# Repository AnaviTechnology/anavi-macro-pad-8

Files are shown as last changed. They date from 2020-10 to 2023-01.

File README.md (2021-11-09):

# ANAVI Macro Pad 8

**Open source, programmable, eight-key keypad with backlighting, underlighting, and OLED screen**

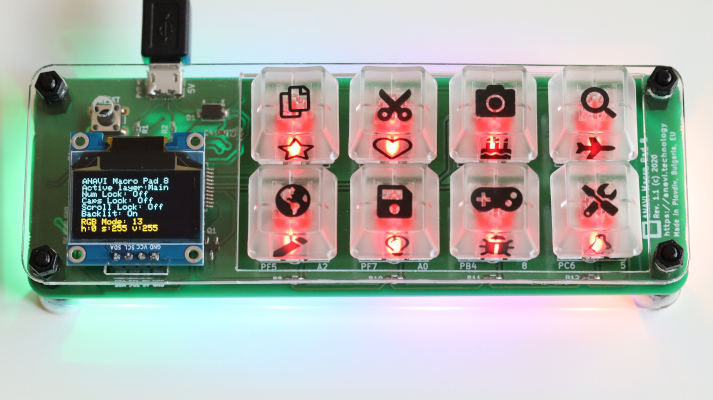
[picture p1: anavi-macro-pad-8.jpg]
ANAVI Macro Pad 8


ANAVI Macro Pad 8 is an open source, custom-programmable, mini 8-key keyboard/keypad. Each key can be reprogrammed to activate a macro or even a dedicated shortcut - all without any coding experience! Powered by the advanced, but easy-to-use [Quantum Mechanical Keyboard (QMK) open source firmware](https://github.com/qmk/qmk_firmware/tree/master/keyboards/anavi/macropad8).

ANAVI Macro Pad 8 has been designed with [the cross platform and open source electronics design automation suite KiCad](https://kicad.org/). [The acrylic enclosure](https://github.com/AnaviTechnology/anavi-cases/tree/master/anavi-macro-pad-8-case) has been designed with [OpenSCAD](https://www.openscad.org/).

[ANAVI Macro Pad 8 was successfully crowdfunded at Crowd Supply on 8 October 2020](https://www.crowdsupply.com/anavi-technology/anavi-macro-pad-8).

ANAVI Macro Pad 8 has been certified by [the Open Source Hardware Association under OSHWA UID BG000072 on July 13, 2020](https://certification.oshwa.org/bg000072.html).

For more details please visit https://anavi.technology/

# License

The project is released under the [Creative Commons Attribution-ShareAlike 4.0 International (CC BY-SA 4.0)](https://creativecommons.org/licenses/by-sa/4.0/).

Note: This is a human-readable summary of (and not a substitute for) the [license](https://creativecommons.org/licenses/by-sa/4.0/legalcode).

You are free to:

Share — copy and redistribute the material in any medium or format Adapt — remix, transform, and build upon the material for any purpose, even commercially. The licensor cannot revoke these freedoms as long as you follow the license terms. Under the following terms:

Attribution — You must give appropriate credit, provide a link to the license, and indicate if changes were made. You may do so in any reasonable manner, but not in any way that suggests the licensor endorses you or your use. ShareAlike — If you remix, transform, or build upon the material, you must distribute your contributions under the same license as the original. No additional restrictions — You may not apply legal terms or technological measures that legally restrict others from doing anything the license permits. Notices:

You do not have to comply with the license for elements of the material in the public domain or where your use is permitted by an applicable exception or limitation. No warranties are given. The license may not give you all of the permissions necessary for your intended use. For example, other rights such as publicity, privacy, or moral rights may limit how you use the material.

You will have to provide a link to the original creator of the project http://www.anavi.technology on any documentation or website.

Credit can be attributed through a link to the creator website: http://www.anavi.technology

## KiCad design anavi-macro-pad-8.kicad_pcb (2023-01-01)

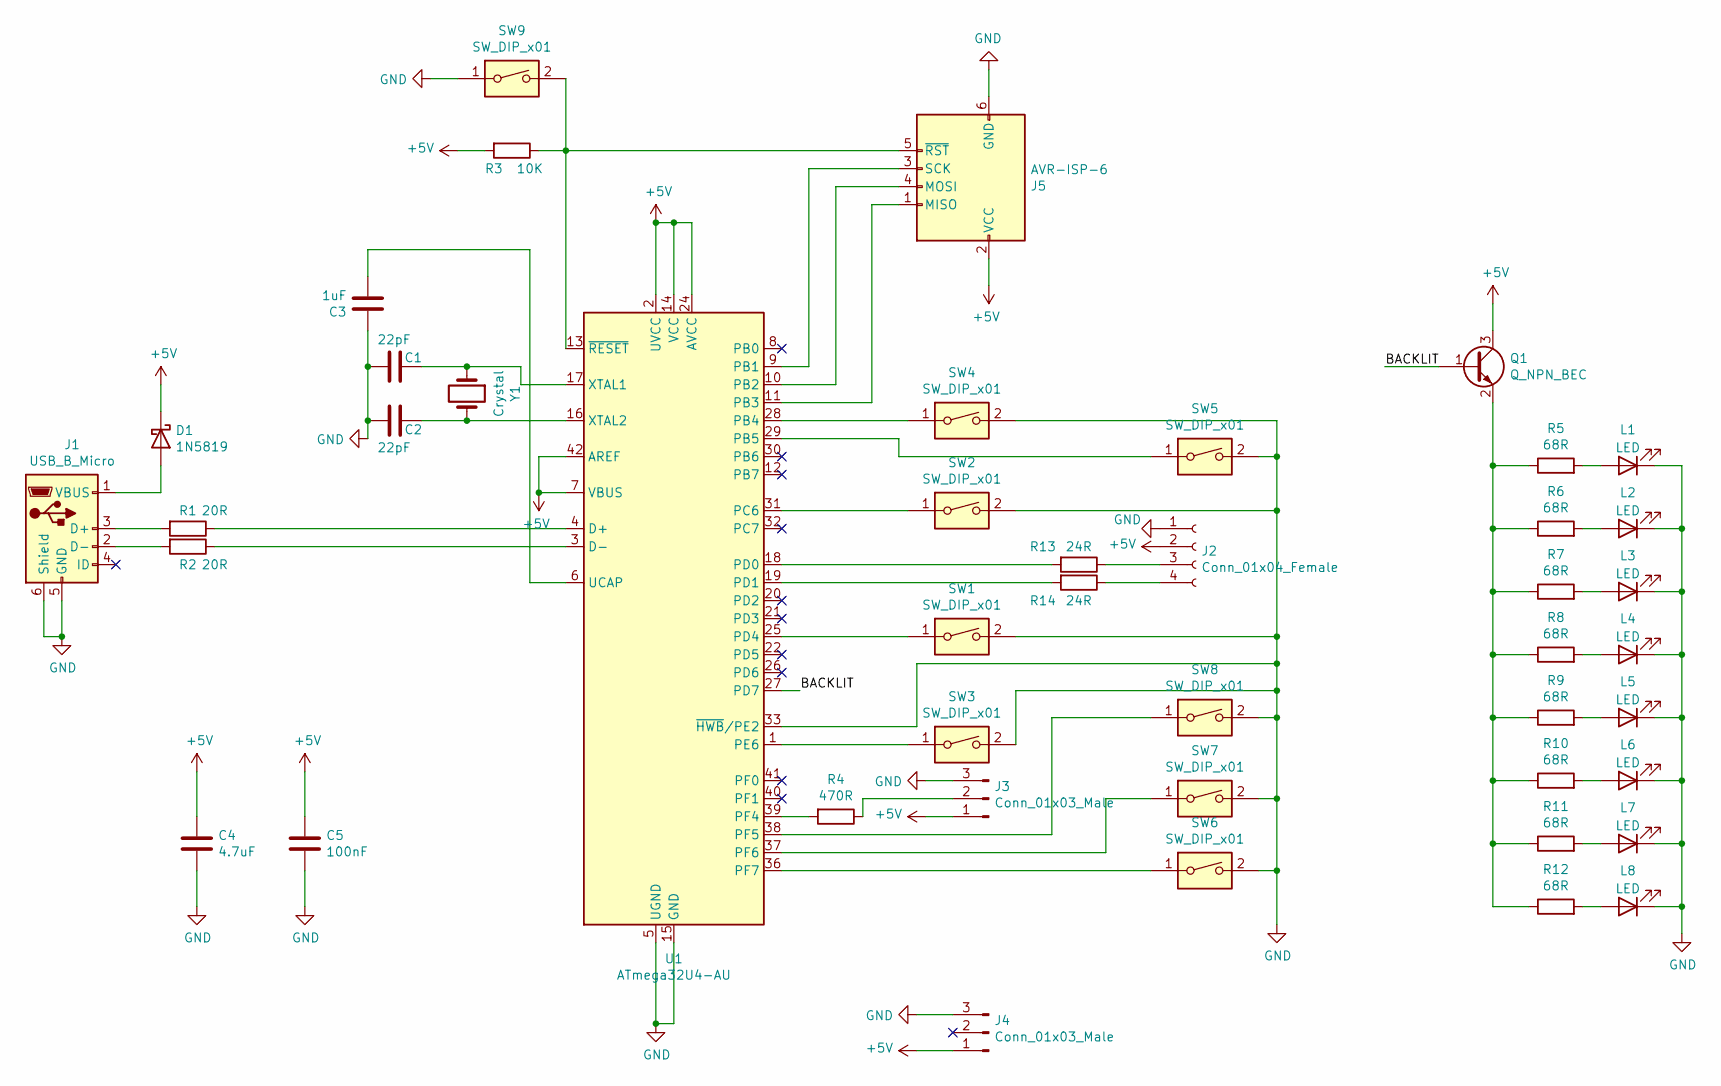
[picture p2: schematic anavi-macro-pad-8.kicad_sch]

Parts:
C1, C2: 22pF; C_0603_1608Metric
C3: 1uF; C_0603_1608Metric
C4: 4.7uF; C_0603_1608Metric
C5: 100nF; C_0603_1608Metric
D1: 1N5819; SMA_Standard
J1: USB_B_Micro; USB_Micro-B_Molex-105017-0001
J2: Conn_01x04_Female; PinHeader_1x04_P2.54mm_Vertical
J3, J4: Conn_01x03_Male; LedConnector_1x03_P2.54mm
J5: AVR-ISP-6; PinHeader_2x03_P2.54mm_Vertical
L1, L2, L3, L4, L5, L6, L7, L8: LED; LED_D3.0mm
Q1: Q_NPN_BEC; SOT-23
R1, R2: 20R; R_0603
R3: 10K; R_0603
R4: 470R; R_0603
R5, R6, R7, R8, R9, R10, R11, R12: 68R; R_0603
R13, R14: 24R; R_0603
SW1, SW2, SW3, SW4, SW5, SW6, SW7, SW8: SW_DIP_x01; SW_Cherry_MX_1.00u_Plate
SW9: SW_DIP_x01; SW_PUSH_6mm_h4.3mm
U1: ATmega32U4-AU; TQFP-44_10x10mm_P0.8mm
Y1: Crystal; Crystal_SMD_3225-4Pin_3.2x2.5mm_HandSoldering

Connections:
+5V: C4.1, C5.1, D1.1 (K), J2.2, J3.1, J4.1, J5.2 (VCC), Q1.3 (C), R3.2, U1.2 (UVCC), U1.7 (VBUS), U1.14 (VCC), U1.24 (AVCC), U1.34 (VCC), U1.42 (AREF), U1.44 (AVCC)
/BACKLIT: Q1.1 (B), U1.27 (PD7)
GND: C1.2, C2.2, C3.1, C4.2, C5.2, J1.5 (GND), J1.6 (Shield), J2.1, J3.3, J4.3, J5.6 (GND), L1.1 (K), L2.1 (K), L3.1 (K), L4.1 (K), L5.1 (K), L6.1 (K), L7.1 (K), L8.1 (K), SW1.2, SW2.2, SW3.2, SW4.2, SW5.2, SW6.2, SW7.2, SW8.2, SW9.1, U1.5 (UGND), U1.15 (GND), U1.23 (GND), U1.33 (~HWB/PE2), U1.35 (GND), U1.43 (GND); also elsewhere on the board
unnamed: C1.1, U1.17 (XTAL1), Y1.1
unnamed: C2.1, U1.16 (XTAL2), Y1.2
unnamed: C3.2, U1.6 (UCAP)
unnamed: D1.2 (A), J1.1 (VBUS)
unnamed: J1.2 (D-), R2.2
unnamed: J1.3 (D+), R1.2
unnamed: J2.3, R13.1
unnamed: J2.4, R14.1
unnamed: J3.2, R4.1
unnamed: J5.1 (MISO), U1.11 (PB3)
unnamed: J5.3 (SCK), U1.9 (PB1)
unnamed: J5.4 (MOSI), U1.10 (PB2)
unnamed 15: J5.5 (~RST), R3.1, SW9.2, U1.13 (~RESET); also elsewhere on the board
unnamed: L1.2 (A), R5.2
unnamed: L2.2 (A), R6.2
unnamed: L3.2 (A), R7.2
unnamed: L4.2 (A), R8.2
unnamed: L5.2 (A), R9.2
unnamed: L6.2 (A), R10.2
unnamed: L7.2 (A), R11.2
unnamed: L8.2 (A), R12.2
unnamed: Q1.2 (E), R5.1, R6.1, R7.1, R8.1, R9.1, R10.1, R11.1, R12.1
unnamed: R1.1, U1.4 (D+)
unnamed: R2.1, U1.3 (D-)
unnamed: R4.2, U1.39 (PF4)
unnamed: R13.2, U1.18 (PD0)
unnamed: R14.2, U1.19 (PD1)
unnamed: SW1.1, U1.25 (PD4)
unnamed: SW2.1, U1.31 (PC6)
unnamed: SW3.1, U1.1 (PE6)
unnamed: SW4.1, U1.28 (PB4)
unnamed: SW5.1, U1.29 (PB5)
unnamed: SW6.1, U1.36 (PF7)
unnamed: SW7.1, U1.37 (PF6)
unnamed: SW8.1, U1.38 (PF5)

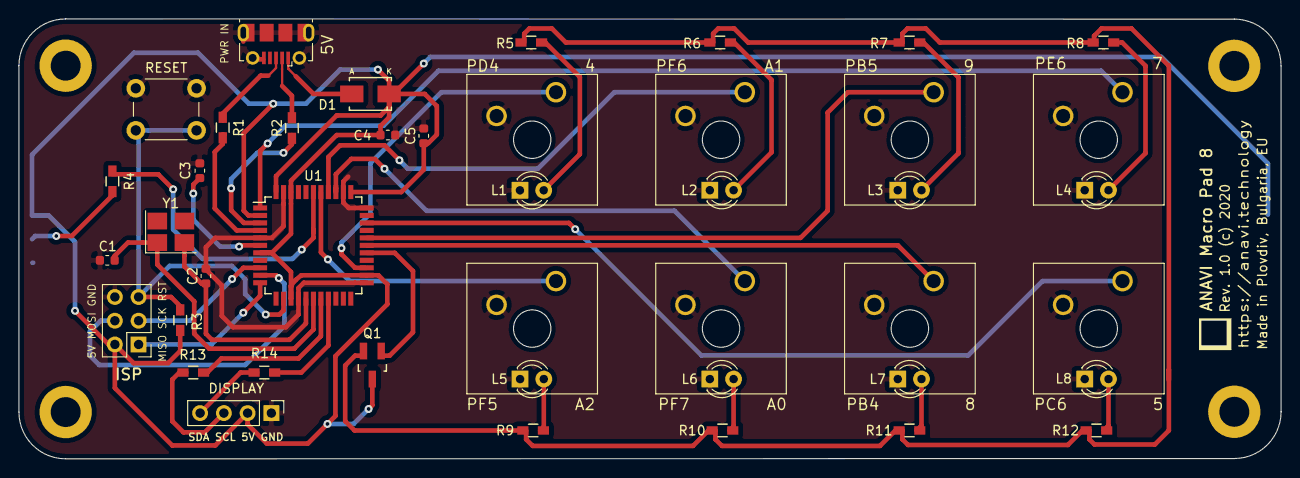
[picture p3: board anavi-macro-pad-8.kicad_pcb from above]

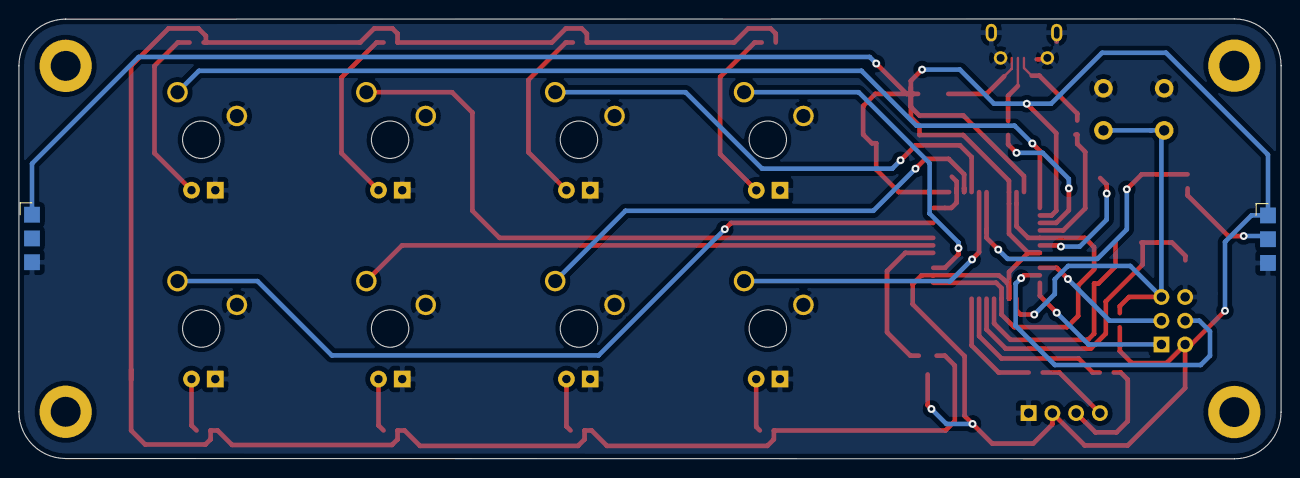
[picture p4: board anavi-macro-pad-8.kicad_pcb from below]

Board: 2 copper layers, 135.0 x 47.1 mm, 45 parts (2 on the bottom side), 38 nets.

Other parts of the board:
RESET: SW_DIP_x01; SW_PUSH_6mm_h4.3mm

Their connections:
GND: RESET.1; also elsewhere on the board
unnamed 15: RESET.2; also elsewhere on the board

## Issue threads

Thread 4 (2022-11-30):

I2C interface is not implemented correctly

HeikoLau, 2022-11-30:
### The resistors R13 and R14 have too large values

The I2C happens to work with the 0.9" OLED supplied. Due to the two 4.7k series resistors, the AVR cannot drive the voltage level to 0V. Nevertheless, the OLED recognises the transmission and sends an ACK. Since the OLED drives the SDA line without series resistors, 0V is reached (SCL=blue curve, SDA=red curve).
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

This does not work with another OLED display (1.3"). The transmission is not even recognised by the OLED and the ACK is missing.
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

The two series resistors in SCL and SDA must be reduced to a maximum of 100 ohms.

### Pull-up resistors are missing

The waveform of SCL and SDA is too slow in the transition from LOW to HIGH. This is caused by missing pull-up resistors. Usually 2.2k are used.

leon-anavi, 2023-01-01:
Hi @HeikoLau,

Thank you for reporting this hardware issue. I have modified the KiCad project to set  the values of the protection resistors used in series on the SDA and SCL lines of the I2C to 24 Ohm. As you noted there are no pull-up resistors so the I2C breakout boards, including these with an OLED display, should take care for them.

Sorry for my late reply on this topic and thank you again for the feedback. In the git commit message I have pointed you out in a `Reported-by:` git trailer.

Thank you for valuable contribution and best wishes for the new year!

Thanks,
Leon

Closed 2023-01-01.

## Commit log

2020-05-02 anavi-macro-pad-8: Initial commit
    Work in progress.
    [anavi-macro-pad-8.kicad_pcb, anavi-macro-pad-8.sch]
2020-05-03 Add outline and arrange components
    [anavi-macro-pad-8.kicad_pcb, anavi-macro-pad-8.sch]
2020-05-03 Add components to the schematics
    The following modificaitons to the schematics and the PCB have
    been done:
    * Added RESET button
    * Added pins for AVR SPI programmer
    * Changed the crystal footprint to 3225
    * Minor modificaitons to the PCB layouts
    [anavi-macro-pad-8.kicad_pcb, anavi-macro-pad-8.sch]
2020-05-03 anavi-macro-pad-8.kicad_pcb: Adjust LEDs
    Adjust the positions of the AVR SPI Programmer, the backlit
    LEDs and the resistors.
    [anavi-macro-pad-8.kicad_pcb]
2020-05-03 anavi-macro-pad-8.kicad_pcb: Initial routing
    Work in progress on the routing of the PCB
    [anavi-macro-pad-8.kicad_pcb]
2020-05-03 anavi-macro-pad-8: Routing with Schottky diode
    Add appropriate footprint for Schottky diode and complete the
    routing of the PCB.
    [anavi-macro-pad-8.kicad_pcb, anavi-macro-pad-8.sch]
2020-05-03 anavi-macro-pad-8.kicad_pcb: Add logo and labels
    Add logo and labels on the PCB.
    [anavi-macro-pad-8.kicad_pcb]
2020-05-04 Minor improvements
    [anavi-macro-pad-8.kicad_pcb]
2020-05-12 anavi-macro-pad-8: Improvements
    Rotate headers to match the direction of the addressable LED
    strip, update labels.
    [anavi-macro-pad-8.kicad_pcb, anavi-macro-pad-8.sch]
2020-05-19 anavi-macro-pad-8.kicad_pcb: Update silkscreen
    Update and improve labels on the front silkscreen.
    [anavi-macro-pad-8.kicad_pcb]
2020-05-19 anavi-macro-pad-8.kicad_pcb: Update 5V labels
    Rotate the labels near the microUSB to match the direction of
    the other labels on the board.
    [anavi-macro-pad-8.kicad_pcb]
2020-05-31 anavi-macro-pad-8.kicad_pcb: Change footprints
    Replace footprints for all resistors and the transistor with
    other same-sized footprints with bigger pads.
    [anavi-macro-pad-8.kicad_pcb]
2021-11-08 Update README.md
    https://forum.kicad.info/t/warning-avoid-all-links-to-kicad-pcb-org-use-kicad-org/31521
2023-01-01 anavi-macro-pad-8: Convert from KiCad 5 to 6
    Convert the project from KiCad version 5 to version 6.
    [anavi-macro-pad-8.kicad_pcb, anavi-macro-pad-8.kicad_sch]
2023-01-01 anavi-macro-pad-8: Fix I2C protection resistors
    Resistors R13 and R14 had too large values. These are protection
    resistors used in series on the SDA and SCL lines of the I2C. To
    fix this issue the values of both resistors were set to 24 Ohms.
    fixes #4
    Reported-by: Heiko Lau <h.lau@ifam-erfurt.de>
    [anavi-macro-pad-8.kicad_pcb, anavi-macro-pad-8.kicad_sch]

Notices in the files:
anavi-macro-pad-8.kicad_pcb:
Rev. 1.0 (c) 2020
